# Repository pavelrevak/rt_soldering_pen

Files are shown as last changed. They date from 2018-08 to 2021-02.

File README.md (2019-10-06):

# RT soldering pen

oled4

[Manual]

This firmware is for my project [RT soldering pen](https://hackaday.io/project/18899-rt-soldering-pen)

You can buy HW at [Tindie](https://www.tindie.com/products/vlk/rt-soldering-pen/)

## Building and flashing

### Requirements

- [`arm-gcc`](https://developer.arm.com/open-source/gnu-toolchain/gnu-rm/downloads)
- [`cmake`](https://cmake.org/download/)
- `make` or [`ninja`](https://github.com/ninja-build/ninja)
- STM flashing SW and HW (ST-Link/V2 or any ST dev-kit, like Discovery or Nucleo board)

Building is possible on Linux, Mac and also on Windows

### Getting source

```sh
git clone --recursive https://github.com/pavelrevak/rt_soldering_pen.git
cd rt_soldering_pen
```

### Building

```sh
mkdir _build
cd _build
cmake -D CMAKE_TOOLCHAIN_FILE=../cmake/arm-none-eabi.cmake -D CMAKE_BUILD_TYPE=Release ..
make
```

### Flashing

Connect ST-Link or other SWD programmer:

#### HW v0.3

- G : GND
- C : SWCLK
- D : SWDIO

#### HW v1.0

- C : SWCLK
- G : GND
- D : SWDIO

If you have installed [pystlink](https://github.com/pavelrevak/pystlink) and is in search path just type:

```sh
make flash
```

If you have another flashing utility you can generate hex of binary file:

```sh
make srec
```

or building also support other targets `hex` and `bin`

Final files are saved in `_build` folder

[manual]: doc/MANUAL.md "Manual"
[oled4]: doc/oled4.png "Screenshot"

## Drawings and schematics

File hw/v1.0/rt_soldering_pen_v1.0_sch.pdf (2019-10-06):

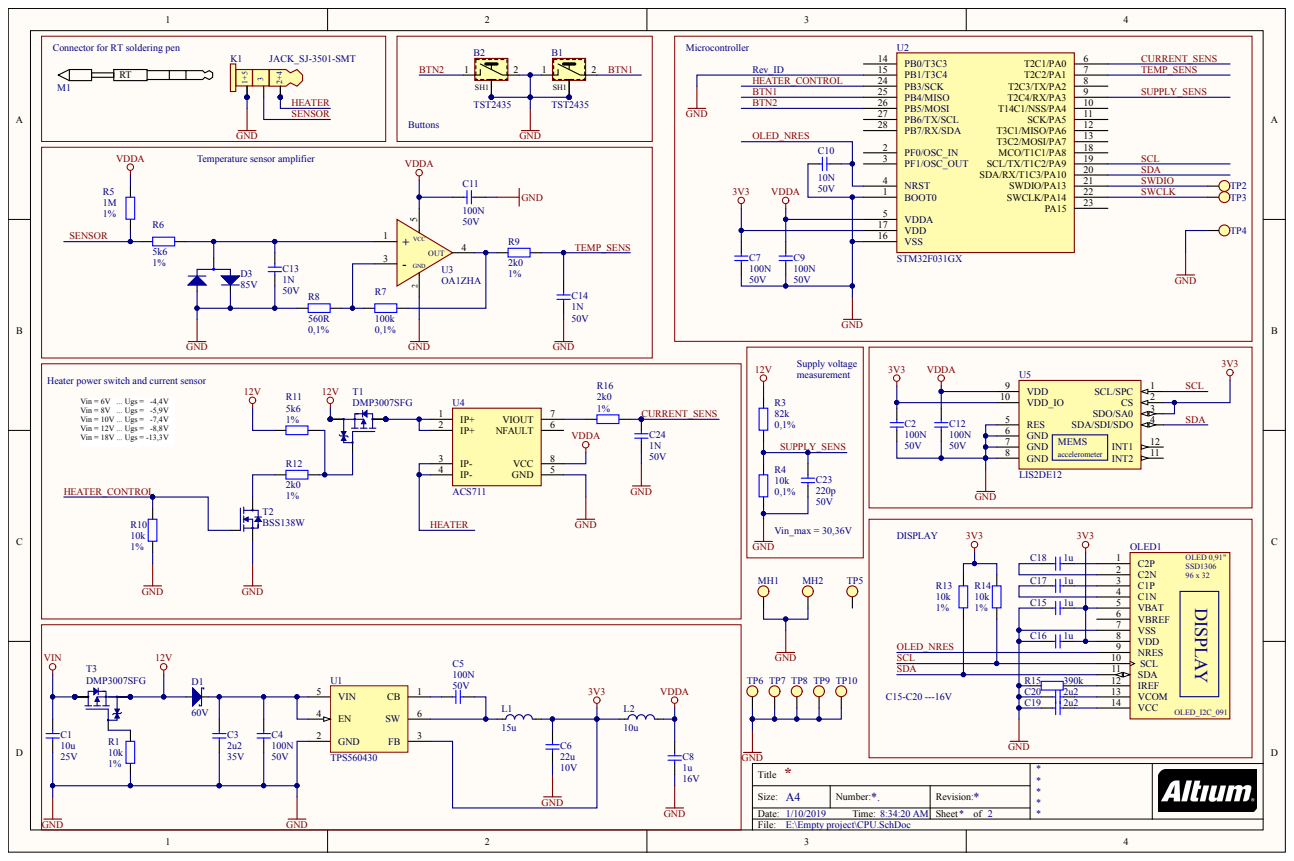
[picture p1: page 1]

Connector for RT soldering pen

Heater power switch and current sensor

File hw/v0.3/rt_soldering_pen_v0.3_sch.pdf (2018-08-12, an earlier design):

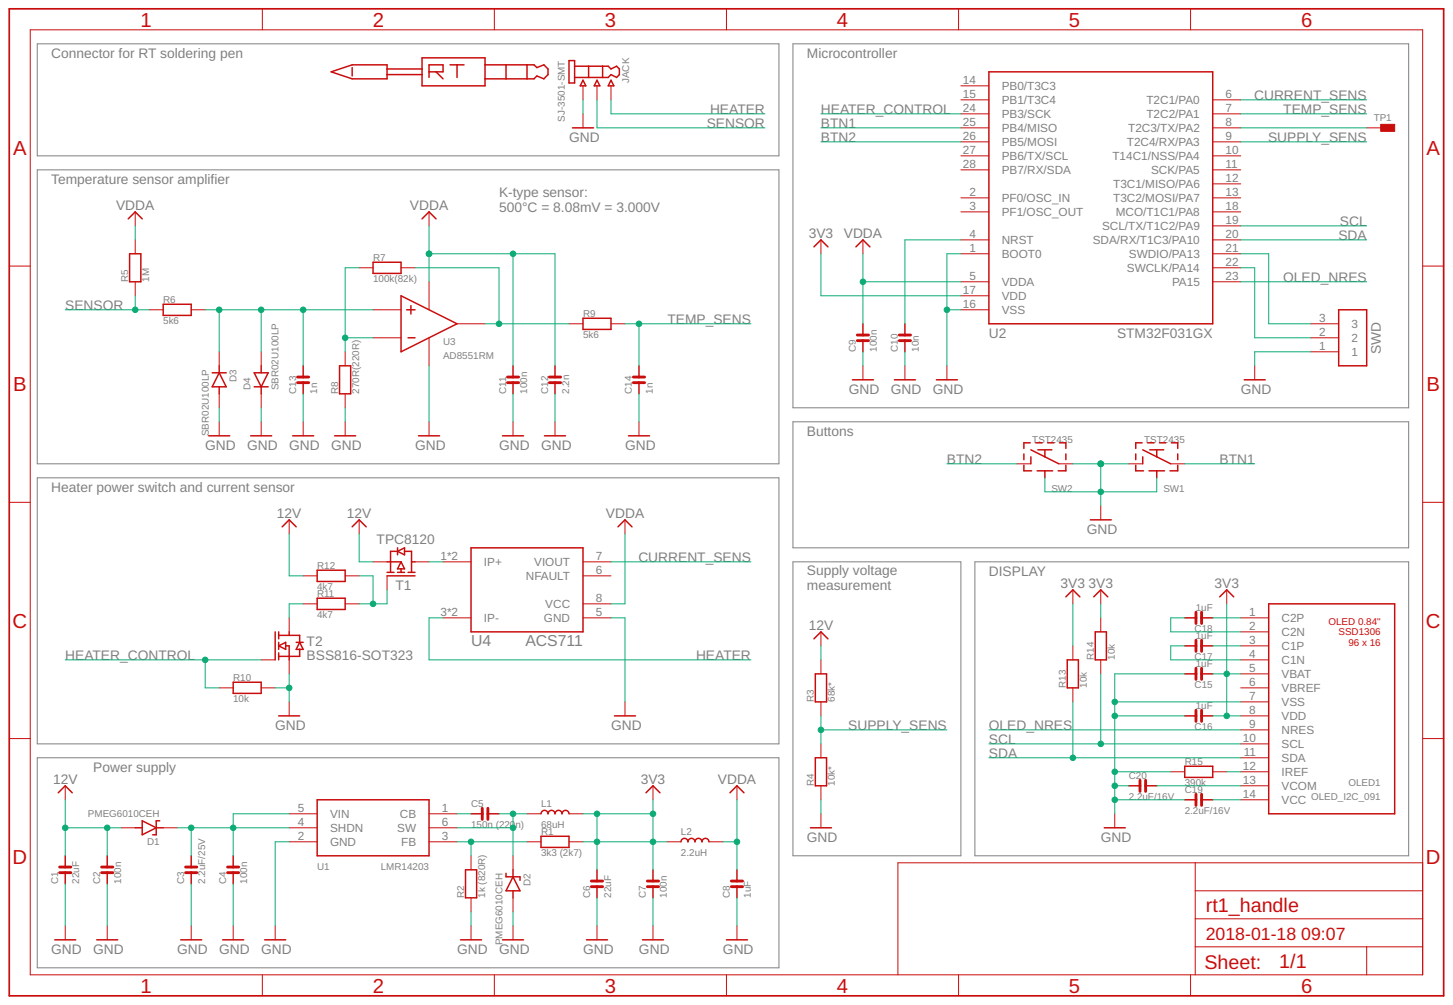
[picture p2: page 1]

17
16

Heater power switch and current sensor

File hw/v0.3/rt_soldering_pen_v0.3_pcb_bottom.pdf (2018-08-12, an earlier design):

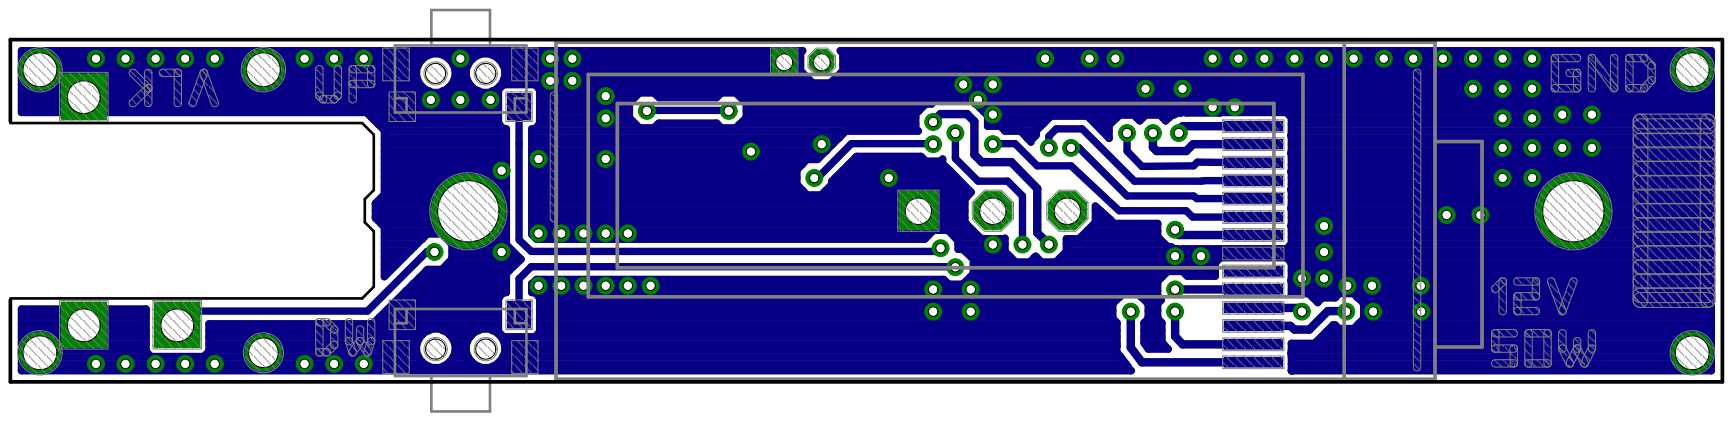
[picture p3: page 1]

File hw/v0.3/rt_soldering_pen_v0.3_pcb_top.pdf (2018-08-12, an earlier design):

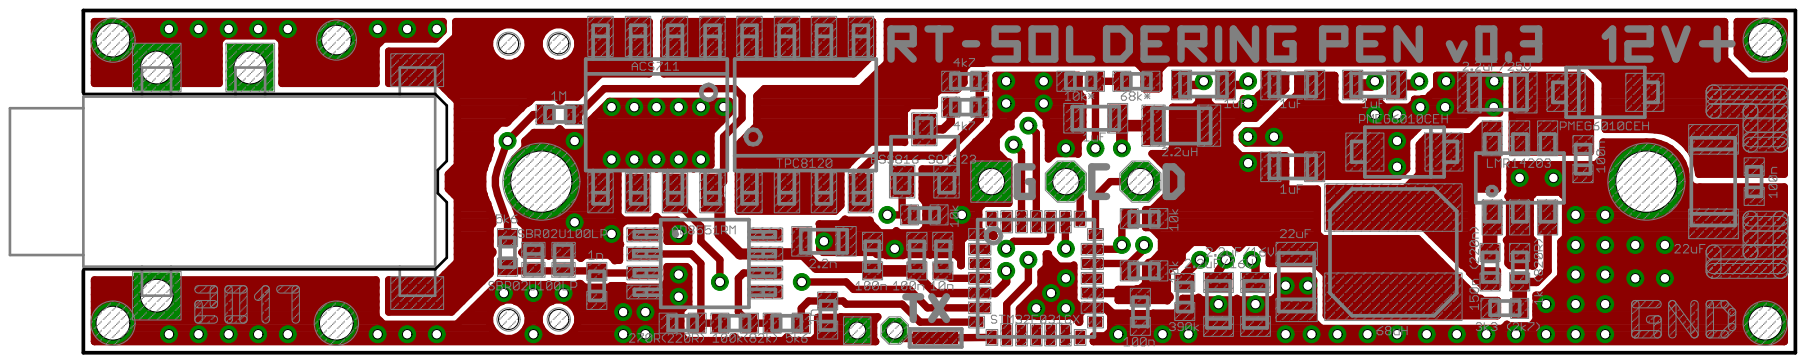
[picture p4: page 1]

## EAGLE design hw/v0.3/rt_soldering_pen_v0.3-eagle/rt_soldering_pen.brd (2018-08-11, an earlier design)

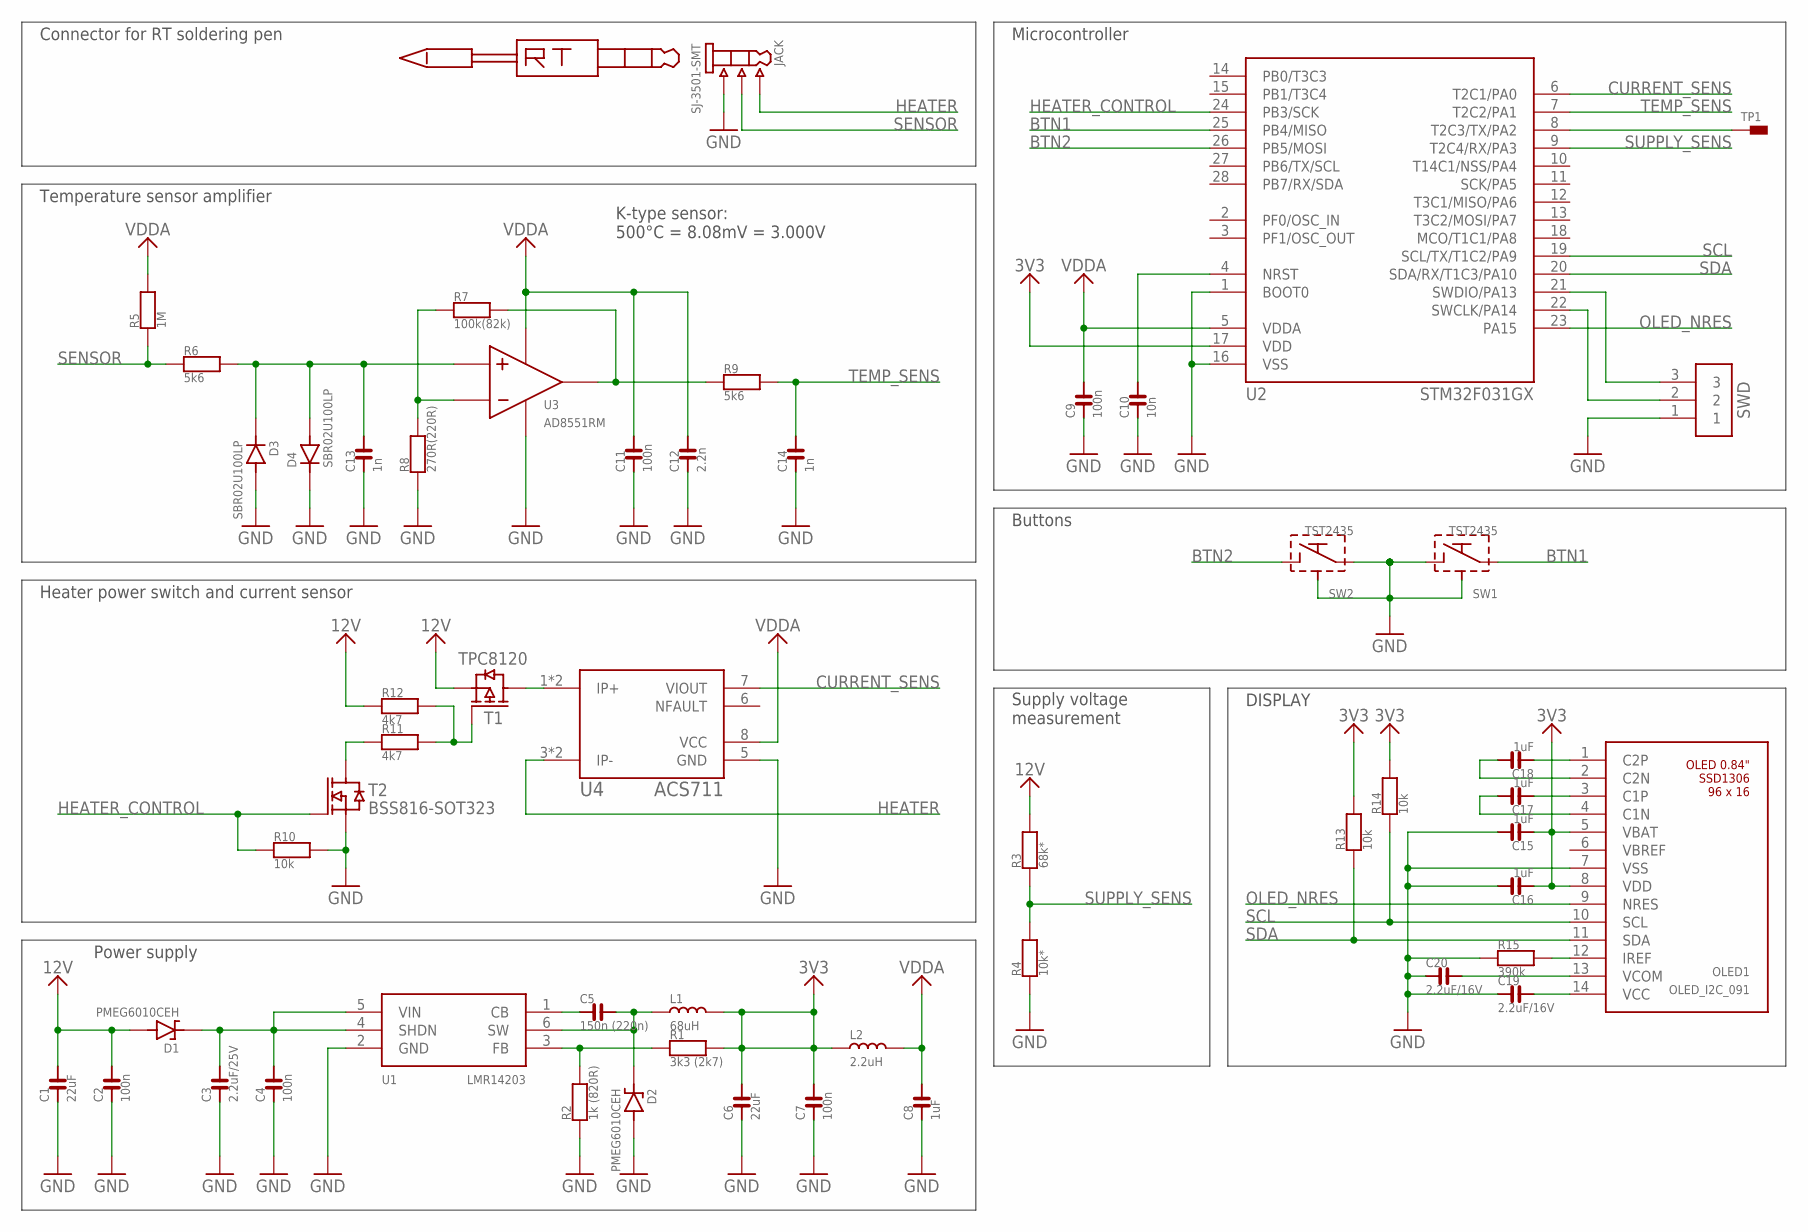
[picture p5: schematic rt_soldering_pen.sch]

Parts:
C1: 22uF; 1206
C2, C4, C7, C9, C11: 100n; 0402
C3: 2.2uF/25V; 0805
C5: 150n (220n); 0402
C6: 22uF; 0805
C8, C15, C16, C17, C18: 1uF; 0603
C10: 10n; 0402
C12: 2.2n; 0603
C13, C14: 1n; 0402
C19, C20: 2.2uF/16V; 0603
D1, D2: PMEG6010CEH; SOD123F
D3, D4: SBR02U100LP; DFN1006
JACK: SJ-3501-SMT
L1: 68uH; 1717
L2: 2.2uH; 0805
OLED1: OLED_I2C_091
R1: 3k3 (2k7); 0402
R2: 1k (820R); 0402
R3: 68k*; 0402
R4: 10k*; 0402
R5: 1M; 0402
R6, R9: 5k6; 0402
R7: 100k(82k); 0402
R8: 270R(220R); 0402
R10, R13, R14: 10k; 0402
R11, R12: 4k7; 0402
R15: 390k; 0402
RT: RT-1
SW1, SW2: TST2435
SWD: PINHEAD1X3X; PIN1X3
T1: TPC8120; SOIC8
T2: BSS816-SOT323; SOT23
TP1: TEST_PAD15X60; SMD_15_60
U1: LMR14203; SOT23-6
U2: STM32F031GX; UFQFPN28
U3: AD8551RM; MSOP8
U4: ACS711; SOIC8

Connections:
3V3: C6.2, C7.2, C15.1, C16.1, L1.2, L2.1, OLED1.5 (VBAT), OLED1.8 (VDD), R1.2, R13.2, R14.2, U2.17 (VDD)
12V: C1.2, C2.2, D1.A, R3.2, R12.1, T1.1 (S), T1.2 (S), T1.3 (S)
12V_DC: C3.2, C4.2, D1.C, U1.4 (SHDN), U1.5 (VIN)
BTN1: SW1.1, U2.25 (PB4/MISO)
BTN2: SW2.2, U2.26 (PB5/MOSI)
C1N: C17.2, OLED1.4 (C1N)
C1P: C17.1, OLED1.3 (C1P)
C2N: C18.2, OLED1.2 (C2N)
C2P: C18.1, OLED1.1 (C2P)
CURRENT_SENS: U2.6 (T2C1/PA0), U4.7 (VIOUT)
DEBUG_OUT: TP1.TP, U2.8 (T2C3/TX/PA2)
GND: C1.1, C2.1, C3.1, C4.1, C6.1, C7.1, C8.1, C9.1, C10.1, C11.1, C12.1, C13.1, C14.1, C15.2, C16.2, C19.1, C20.1, D2.A, D3.A, D4.C, JACK.1, JACK.5 (1), OLED1.7 (VSS), R2.1, R4.1, R8.1, R10.2, R15.1, SW1.2, SW1.EP1 (SHIELD), SW1.EP2 (SHIELD), SW2.1, SW2.EP1 (SHIELD), SW2.EP2 (SHIELD), SWD.1, T2.2 (S), U1.2 (GND), U2.1 (BOOT0), U2.16 (VSS), U3.4 (V-), U4.5 (GND)
HEATER: JACK.2, JACK.4 (2), U4.3 (IP-), U4.4 (IP-)
HEATER_CONTROL: R10.1, T2.1 (G), U2.24 (PB3/SCK)
HEATER_PWR: T1.5 (D), T1.6 (D), T1.7 (D), T1.8 (D), U4.1 (IP+), U4.2 (IP+)
IREF: OLED1.12 (IREF), R15.2
NRST: C10.2, U2.4 (NRST)
OLED_NRES: OLED1.9 (NRES), U2.23 (PA15)
POWER_SWITCH: R11.2, R12.2, T1.4 (G)
POWER_SWITCH_LOW: R11.1, T2.3 (D)
SCL: OLED1.10 (SCL), R14.1, U2.19 (SCL/TX/T1C2/PA9)
SDA: OLED1.11 (SDA), R13.1, U2.20 (SDA/RX/T1C3/PA10)
SENSOR: JACK.3, R5.1, R6.1
SENSOR_FEEDBACK: R7.1, R8.2, U3.2 (IN-)
SENSOR_IN: C13.2, D3.C, D4.A, R6.2, U3.3 (IN+)
SENSOR_OUT: R7.2, R9.1, U3.6 (OUT)
SUPPLY_CB: C5.1, U1.1 (CB)
SUPPLY_FB: R1.1, R2.2, U1.3 (FB)
SUPPLY_SENS: R3.1, R4.2, U2.9 (T2C4/RX/PA3)
SWDCLK: SWD.2, U2.22 (SWCLK/PA14)
SWDIO: SWD.3, U2.21 (SWDIO/PA13)
SWOUT: C5.2, D2.C, L1.1, U1.6 (SW)
TEMP_SENS: C14.2, R9.2, U2.7 (T2C2/PA1)
VCC: C19.2, OLED1.14 (VCC)
VCOM: C20.2, OLED1.13 (VCOM)
VDDA: C8.2, C9.2, C11.2, C12.2, L2.2, R5.2, U2.5 (VDDA), U3.7 (V+), U4.8 (VCC)

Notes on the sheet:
K-type sensor: 500°C = 8.08mV = 3.000V
SWD
Power supply
Heater power switch and current sensor
Temperature sensor amplifier
Connector for RT soldering pen
Microcontroller
DISPLAY
Supply voltage measurement
Buttons

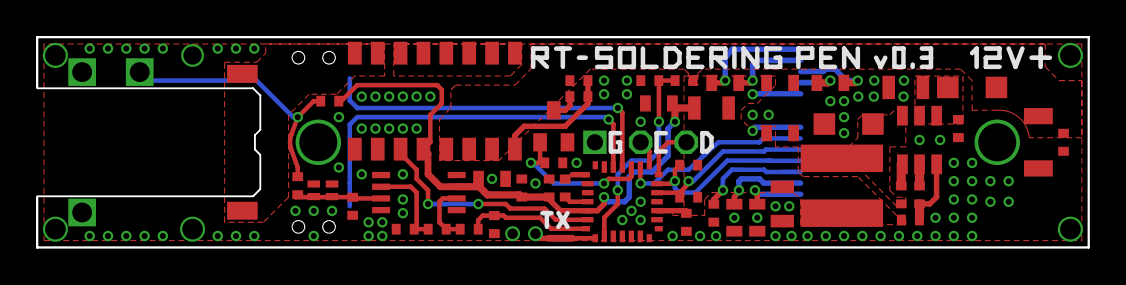
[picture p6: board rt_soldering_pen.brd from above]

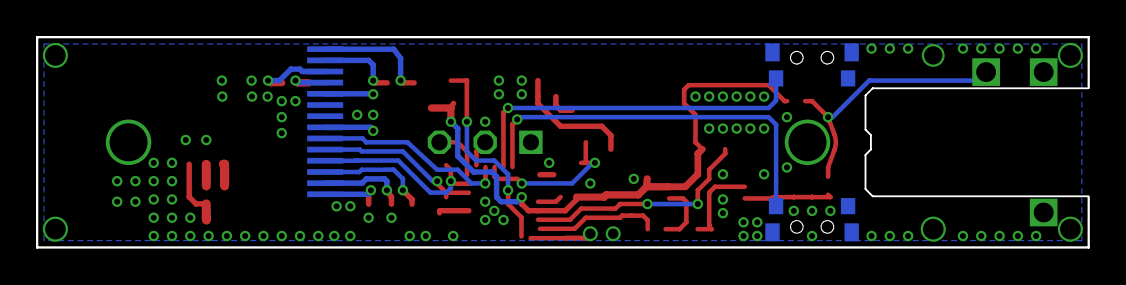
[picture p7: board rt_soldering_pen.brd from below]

Board: 2 copper layers, 58.4 x 11.7 mm, 54 parts (3 on the bottom side), 36 nets.

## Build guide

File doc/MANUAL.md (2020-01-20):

# RT soldering pen MANUAL

## Specs

- Supported pens: all Weller RT (RT, RTM, RTP and RTU) tips with 3.5mm JACK
- Operating voltage: 5 - 24V, recommended maximum:
  - 13V for RT, RTM and RTP tips
  - 24V for RTU tips
- absolute maximum voltage: 25V
- Supply current: pulse peaks to 6A @12V (average resistance of RT heating elements is 2 Ohm, so current depends on supply voltage)
- Supply current in idle: max 15mA
- Regulation: PSD (PID) regulator with PWM power transfer (125ms period)
- Set-point temperature: 50°C - 500°C (400°C with old HW v0.3)
- Maximum measurable tip temperature: 999°C (530°C + ambient temperature with old HW v0.3)
- Maximum heating power: is limited by SW to 40W or by supply voltage:
  - 20W @7V, 40W @10V (with RT, RTM and RTP tips)
  - 12W @7V, 40W @13V (with RTU tips)
- Heating speed: 30°C -> 300°C: about 4s with RT-2 pen and 40W limit
- Temperature accuracy: about +/-5°C
- Other features:
  - Celsius / Fahrenheit
  - right / left handed mode
  - normal / advanced mode display
  - High brightness mode
  - Auto turn off display to prevent OLED burning
- FW updating: by any SWD programmer (ST-Link) [actual firmware](https://github.com/pavelrevak/rt_soldering_pen/releases), firmware is still under active development.

## Powering

- supply pins are marked with GND, - or BLACK wire as negative pole and +12V, + or RED wire as positive pole.

### WARNING

- **Always check if RT tip is fully inserted before turning ON heating.** If is not fully inserted, then temperature measuring is not working and tip can be overheated. Protection for this will be created in future SW releases.

- on old HW v0.3 **be careful with connecting supply and always check polarity before turning ON!**
  - Although MCU is protected for reverse voltage by diode, power part is not protected. **If is connected RT tip, with reversed voltage then will heat on maximum power and also MOSFET transistor will overheat.** (this is for HW v0.3)
  - HW v1.0 has full reverse voltage protection with FET diode

- **Do not solder something under voltage if is powered from same supply, because RT tip is connected with GND. (for example inside car when pen is powered from lighter connector, or some AC power supplies where is negative pole connected to ground conductor).**
  - **MS** (Military Specs) tips have isolated tip from ground.

### Supply from AC power supply

Switching power supplies must be able to withstand high current pulses (12V/6A). These supplies has almost always connected negative pole with protective conductor.

Or you can use Transformer with good capacity and these supplies don't have connected minus pole to ground conductor.

### USB-C USB-PD

For that exists ZYPDS and similar modules - it is a converter from USB-PD to selected output voltage and current. But this is not tested and it should have some problems, because all the supply voltage is switched with PWM to 2 ohm load (inside RT tip) so: for 12V it is almost 6 Amps and in normal USB-PD is maximum rating 5A but only at 20V.

### Supply from battery

Best batteries for supply RT soldering pen are hobbyist LIPO 3S or 2S (but not full output power) with capacity at least 1Ah (with continuous discharge current at least 5A).

From my practice 2.2Ah 3S LIPO battery can last for about 5 to 10 hours of soldering.

### Hybrid power supply battery/USB(AC)

Also is possible to use small 3S LIPO battery about 0.5Ah / 20C and this battery will be continuously charged with small charger - steup-up from USB 5V (about 0.5A charging current) - this battery will work as capacitor with very high capacity. For that is enough also standard and cheap USB. and also is possible to work for some time without USB supply.

## Buttons

RT soldering pen has only two buttons: **UP** and **DOWN**. Firmware recognize different pressing states and combinations.

### Pressing states

- **PRESS** press button shortly (shorter than 1 sec) after release will be generated action
- **LONG** hold button longer than 1 sec, after 1 sec will be generated action "long"
- **HOLD** hold button and after 1 sec will be generated repeat actions

### General operating principles:

| | **UP** | **DOWN** | **BOTH** |
|---|---|---|---|
| **PRESS** | select, increase, scroll | select, decrease, scroll | heating off, exit menu  |
| **HOLD**  | edit | edit | enter menu, change item |
| **LONG**  | scroll, increase | scroll, decrease | - |

## Screens

Actually there are two screens.

### Main screen

#### Normal mode

oled6

Show very basic information

- preset temperatures and selected preset (with arrow)
- actual TIP temperature (if no TIP is attached, `--` is shown, if is detected error on pen, `Err` is shown)
- bar-graph - actual heating power.

#### Advanced mode

oled3

Show some verbose information:

- preset temperatures and selected preset (with arrow)
- actual TIP temperature (if no TIP is attached, CPU temperature is shown)
- consumed energy (this is restarted with power cycle)
- status
  - `NO RT TIP` - RT TIP is not attached (or TIP has broken temperature sensor)
  - `STANDBY` - standby mode (no heating), if blink: temperature is over 50°C
  - `IDLE` -  if during heating is not detected any work, after 5 sec is shown this message and after 30 sec is set standby mode
  - `OVERHEAT` - temperature of the TIP is higher than 500°C. (this can hapened due an error) if high temperature is detected, immediatelly is put into standby.
  - `BROKEN RT TIP!` - TIP has broken heating element (heating element resistance is more than 100 Ohm)
  - `SHORTED RT TIP!` - TIP has shorted heating element (heating element resistance is lower than 0.5 Ohm)
- actual heating power
- supply voltage
- supply voltage drop - show dropped voltage of power supply during heating, generally it depend on power supply resistance and resistance of wires

oled1
oled2
oled4

#### Left handed mode

Display is upside down, also with some rearrangements.

oled7
oled8

#### Editing preset temperatures

On **Main screen** are two (up and down) preset values, which you can easily change.
Editing is visible by blinking appropriate preset value.

**Entering edit mode:**

- **LONG** press **UP** or **DOWN** button of the appropriate preset temperature.

**Changing the edited preset temperature:**

- **UP** or **DOWN** button.

**Exiting edit preset value:**

- **PRESS** **BOTH** buttons.

### Menu screen

oled5
oled9

This screen show simple menu with:

- version information
- basic settings:
  - High Brightness
  - Advanced mode
  - Fahrenheit
  - Left handed
- some verbose information:
  - Total power
  - Heater power
  - Heater current
  - Heater resistance
  - CPU temperature
  - CPU supply
  - Current sensor error

**Entering menu screen:**

- in main screen **LONG** press of **BOTH** buttons

**Scrolling main screen**

-  **UP** or **DOWN** button

**Changing ON/OFF values:**

-  **LONG** press of **BOTH** buttons

**Exiting menu screen:**

-  **PRESS** **BOTH** buttons

*Exiting menu screen also store settings*

[oled1]: oled1.png "Screenshot"
[oled2]: oled2.png "Screenshot"
[oled3]: oled3.png "Screenshot"
[oled4]: oled4.png "Screenshot"
[oled5]: oled5.png "Screenshot"
[oled6]: oled6.png "Screenshot"
[oled7]: oled7.png "Screenshot"
[oled8]: oled8.png "Screenshot"
[oled9]: oled9.png "Screenshot"

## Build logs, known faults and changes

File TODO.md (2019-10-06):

### SW:
- ~~control display brightness~~
- ~~turn off display after long inactivity~~
- detect broken current sensor
- not fully inserted tip protection
- use current sensor magnetometer to enter sleep mode (magnet near the current sensor will enlarge offset error)
- use thermocouple type D curve to calculate tip temperature (it increases temperature measuring accuracy)
- standby should not blink if raw tip temperature is less than 10°C although tip temperature is higher than WARN_HOT_TIP_TEMP (50°C)
- overheating detection by temperature sensor
- in Fahrenheits mode increment by 5°F and round current temperature to 5°F
- I2C Read support
  - use temperature sensor in accelerometer instead sensor in CPU (HW v1.0)
  - use accelerometer to WAKE-UP (HW v1.0)
  - use accelerometer to detect free fall to turn OFF (HW v1.0)
- menu settings allow edit values
  - move PID and other constants to settings menu
  - configure maximum power output
- create screen "INFO" and move all information values there
- tool to tune PID regulation
- improve IDLE detection
- room to improve PID
- under voltage for LiPO protection
- screen saver ?

### HW:
- fix wrong connection to current sensor

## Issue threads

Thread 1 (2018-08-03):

Not issues but wishes

Kabron287, 2018-08-03:
Nice product
1. Accelerometer is higly desirable like in TS100
2. Go to Stanby Time adjustable from settings.

pavelrevak, 2018-08-08:
Adjustable standby timeout is planed feature
Accelerometer , there is no space on PCB, this need redesign.

Kabron287, 2018-08-08:
No need to redesign. Due to low pin-count it can easy placed on free PCB space and hand-wired.
You need Just to add the code.

pavelrevak, 2018-08-08:
yes, it is possible, but not for all devices ,-)

Kabron287, 2018-08-08:
What all devices?
On start SW search I2C if found MMA8652FC it use it, else not.

pavelrevak, 2018-08-09:
Ok, Now I understand what you want.
Yes, this is good idea and personally I also thought about it in the past, but at this moment there is still lot of work with the software. so, I need to postponed the idea for later.

pavelrevak, 2018-08-09:
But if you need something like "auto-standby" mode, there is still one possibility and without HW change. the current sensor also react on surrounding magnetic field (this magnetic field is compensated and subtracted from final measured current, but this "error" is possible to use for detect near magnetic field, so my idea is to put into stand small magnet which will be placed nearly to the current sensor location and if I detect higher magnetic field I put the iron into standby and if the field will lost I immediately wake up. this will be more easier.

Kabron287, 2018-08-09:
Good idea for a moment

pavelrevak, 2018-08-09:
You can see the magnetic field acting on the sensor in menu under: `Current sensor err:`

x893, 2018-08-11:
Hi,
possible change
1. ACS711ELCTR-12AB-T to ACS711KEXLT-15AB-T
2. LMR14203+1717+PMEG6010CEH to LMZM23600

pavelrevak, 2018-08-11:
Hi, thanks for suggestions.
Regarding ACS, I previously try to make design with this one, but with QFN it was much harder to layout it on two layer PCB, although it is smaller package, SO8 has so much space under package, so there was not a problem to wire other signals.
And LMZM23600 ... yes, I was looking on this one, but when I started the design it was problem to buy it, because it was very new and also has some special requirements from PCB.

Kabron287, 2018-08-16:
Made a simple case with the acrylic tube 16mm.
I had to make small recesses for the buttons.
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

elektrinis, 2018-09-01:
+1 for accelerometer. Bit frustrating to find it cold each time.

Also, is it possible to implement supply from USB C PD? There are several examples on github how to setup the USB for 12V 6A and it seems to be fairly simple. This would be extremely useful!

Kabron287, 2018-09-01:
**_There are several examples on github how to setup the USB for 12V 6A_**
Interesting, would you be kind to give some links?

elektrinis, 2018-09-01:
Arduino project: https://github.com/ReclaimerLabs/USB_PD
Other: https://github.com/ReclaimerLabs/USB-PD-Breakout
I also saw one for STM, can't find it quickly.

Kabron287, 2018-09-02:
Something have to be done with the current limitation alhoritm. Due to the very high starting current, most power supplies go into protection. There are not such behaviour in TS100 and TS80.
I guess soft start with variable PWM duty cicle required.

elektrinis, 2018-09-02:
I have also noticed that heater is being switched very slowly. You should PWM it at 16kHz, like most power electronics.

pavelrevak, 2018-09-04:
PWM period is 150ms, there are more reasons for that
1. low EMI
2. I can not measure temperature if power switch is ON, and after OFF I need wait at least 2ms (to stabilise temperature measure amplifier) and then measure for at least 8ms (there is more measurements for averaging) and to keep good duty cycle to maximise power if supply voltage is below 12V I need to make longer PWM.
3. also in every cycle I recalculate all measured values, calculate PID, redraw display with newly measured values, ..

Your power supply MUST withstand 2Ω load (e.g. 6A at 12V or 8A at 16V)
TS100/80 has higher heater resistance, so there is lower current.
I think TS100/80 has also low frequency PWM.

elektrinis, 2018-09-05:
Thank you for explaining. Not criticizing, just want to understand the issue better.
I have a fair amount of experience with BLDC/AC motor drives that usually run at 16kHz PWM and do much more measurements and calculations than in this case (read on FOC). The trick is to let PWM run on it's own dedicated timer-based peripheral, also use a peripheral to synchronize measurements at start of off state and then have your calculations running independently. Main objective is to free your CPU time by not micromanaging the PWM and only relatively infrequently updating cycle width. When you have high PWM frequency, you don't need to recalculate cycle-by-cycle.
Adding a small capacitor and, perhaps, inductor, will take care of EMI and will also allow to use lower power supply.

pavelrevak, 2018-09-05:
Yes, thats true, but there is still problem with thermocouple, which give only 8mV at 500°C this has common ground with heating element. and amplifier has some filters, so I need wait some time when it stabilise.
Another problem is that I used MOSFET with very low Rds-on but has one disadvantage that is slower and with higher frequencies will be not fully switched and then it will generate more heat. and this is another problem that I need to keep PCB cool as much as possible, because inside MCU is temperature sensor, which measure second end thermocouple (also reason why MCU is running on 8MHz and not at 48MHz).
I Have plan to try decrease period to about 50ms to have faster response of PID but I will do it later.

Regarding MCU there is also possibility to use STM32L031G6 which is pin compatible and has lower power consumption.

Or if you have some experience and time, you also can try to play with this, source is available.

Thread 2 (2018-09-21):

Eagle Mosfet lbr missing

Broatcast, 2018-09-21:
You missed to add your mosfet lbr to the repo. ;)

pavelrevak, 2018-10-23:
Done
51f855a429d37314537b0ec9da5aaea6c12ac7bc

Closed 2018-10-23.

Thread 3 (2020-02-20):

Hacking up a case - what screws?

qu1j0t3, 2020-02-20:
Hi,

I don't have the software to open your engineering drawings, so I was wondering if you can tell me if **M2** screws will definitely fit the two large pcb holes that seem to be about 2mm ø.

The clearance top and bottom looks to be less than 3mm so I am planning on using 3mm nylon spacers on both sides.

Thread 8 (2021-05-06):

Feature Request: Power-On-Demand Mode

wolfpackmars2, 2021-05-06:
POD mode.

An alternative mode where the iron is powered while pressing one of the buttons and shuts off when the button is released. The irons heat up quickly enough that this mode should be bearable for small soldering jobs. When pressed, the iron will wake and begin heating to it's set temp and then maintains that temp until the button is released, where the iron will power down.

In lieu of an audible alert when the set temp has been reached, flash "READY" in large print of the OLED.

To modify configuration while in this mode, press and hold both buttons for 3s, where the controller will wake and allow changing temperature/Mode/other parameters without heating the iron.

Can switch between Power-On-Demand/Standard modes in config.

Motivation: Increase efficiency when running iron from battery power.

I admit I have just received my first unit and haven't had much time with it, so I'm not familiar with the current features and operation. I DID want to document this thought while it was fresh in my mind.

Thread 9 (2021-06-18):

problem with RTM tip

messschuh, 2021-06-18:
i use the v.03 HW since round 3 years most time with RT8MS tip, now i got a new one, the RTM032S and they work a bit strange.
the temperature is not stable(+/- 10°) like the RT8MS (+/- 3°) and the powerregulation seems diffrent. at freeair the RT8MS power is nearly stable at round 3W, with the RTM032S  the power alternates from 0W to 6W to 0W @ round 3 seconds and with this tip the pen never detect an idle and because of this never goes to idle mode.
 the heat resitance shown at oled is for RTM032S 1.8Ohm and for RT8MS 2.1Ohm.  i testes SW v0.4.0 and v0.3.0 without diffrents.
only part of code i changed was the heating power, i reduced it to 35W because of 2 burned tips in the last 2 years.
i dont think this is normal, is this a known issue of this tip? can i try something?

swissfreek, 2021-06-18:
A friend of mine has also had three or four tips burn up over the past year. The issues I’ve identified with him is that he runs it at 400° Or more all the time to compensate for the (relatively) lower power compared to like an 80W soldering station. I never run mine higher than 400° and haven’t had a problem. I suspect these tips don’t like being run at high temp for long periods of time

pavelrevak, 2021-06-18:
RTM tips are very small, there is hard to tune PID regulation loop for all range of tips, for this tiny tip you can try to decrease amplification of all constants in PID (heating.hpp: PID_K_...)

messschuh, 2021-06-19:
thanks for fast reply.
most time i use mine at a range of 330°-360°C, for harder soldering jobs i use my 80W station. i´m not really sure constant high temperature  was problem of burning my tips, i will try it with the reduced Power (35W) and will see what happens.

what did u mean with "this tiny tip" ? the tips at all or especialy the RTM032S, because the RTM032S is a bit bigger than the RT8MS.
Ok, i tried some diffrent PID vlaues and now i have setting that works for me. I decresse P and I to 350, 300 and increase D to 75. now it needs a bit more time to get stable temperature but the settings works with my old and the new tip. maybe some finetuning is needed to get it works perfect, but for the moment it is ok.

pavelrevak, 2021-06-19:
Ah, I'm sorry, RTM032 is bigger, I was wrong with another RTP, which is smaller. but yes, it can help to tune the PID constants.

it will be good idea to make these constants editable from menu for fine-tune

messschuh, 2021-06-19:
yes  thats a good idea, maybe another good idea is to implement a PID autotune function. i know PID autotune from 3d-printers and that works well. but i dont know it  would pe possible to implement it.

messschuh, 2023-04-11:
short reply after nearly 2 years, no burned tips again and the "new" PID-settings works well. just at "higher" voltage ( 4s- range) the PID´s do not work perfect but acceptable good.

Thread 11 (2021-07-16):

WTF with stl???

Kabron287, 2021-07-16:
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
Maybe you had to warn about?

swissfreek, 2021-07-16:
The case was designed to be used with wires connected directly coming out the back of the PCB, to a battery connector (mine has about a meter of 22ga two-strand bonded silicone wire coming out the back with an XT60 at the end). For that, the ones I have printed come out fantastic. They have an absolutely perfect fit to the PCB. For your use, it would probably not be very hard to cut off the last five milimeters or so of the case and maybe carve the hole out a little bigger to fit your connector.

Kabron287, 2021-07-16:
Your stl files are for V1, mine is 0.3
They are not compatible!
That must be stated out!!!

swissfreek, 2021-07-16:
Sorry man, just trying to help. I'm not the one who created the project (that's Pawel Revak) and I'm not the one who designed the case (that's Otto Winter). However, the page does say that it's meant for HW v1.0:

https://hackaday.io/project/18899-rt-soldering-pen/log/171690-rt-pen-case

Kabron287, 2021-07-16:
Forget about. OLED is dead after trying to fit in this case

Kabron287, 2021-07-16:
What is OLED part number?

swissfreek, 2021-07-16:
Aw man, that sucks! I actually had the same thing happen to me as well. Even with HW 1.0, the cutout for the screen is off by a millimeter, maybe even less, and it will crack the edge of the screen if you force it. Pawel said Otto used a prototype version of the board, so it's a little off. On the plus side, it's fairly easy to replace the screen. I used this that I was able to get off Amazon overnight (I'm in the US).

https://www.amazon.com/Pieces-Display-Module-SSD1306-Screen/dp/B08TLXYKS6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

Downside is that I had to desolder it from the breakout board first, so it was extra work, but I didn't feel like waiting a month for a bare panel to ship to me from China. Once I replaced the screen, the trick is to put the screen in the case before you stick it down to the PCB with the double-sided tape. This way it will position itself properly and then you won't have a problem anymore.

swissfreek, 2021-07-16:
By the way, if you do buy the screen already attached to a breakout board like I did, a little heat will help release the double-sided tape without cracking the screen again. But be very careful with the heat, as it can affect the crystals in the screen. Just use a very tiny bit for a short time, that's all it takes.

Kabron287, 2021-07-16:
On the schematic it marked as 0.84" 96x16, but in you link it is 0.91"
Which is correct?

swissfreek, 2021-07-16:
I have HW v1.0, and I bought what I linked, and it fit perfectly, 1-for-1 replacement. If you have HW v0.3, it might use a smaller/lower res display, I'm not sure.

pavelrevak, 2021-07-16:
v0.3 also has 0.91, (it is mistake in schematic) for both is possible to put also 0.84 (16x96), but software is made for only 0.91 (32x128)

Kabron287, 2021-07-16:
I guess corrections will follow

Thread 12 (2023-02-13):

can you publish v1.1 HW info?

eliocor, 2023-02-13:
Since it is almost 2 years the Tindie shop does not offer anymore your soldering pen, will you be so kind to publish the v1.1 schematics and (if possible) the gerbers of the new PCB?

paciotti, 2023-02-22:
It will be really appreciated!

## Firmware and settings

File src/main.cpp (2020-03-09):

#include "io/reg/cortexm/nvic.hpp"
#include "drv/watchdog.hpp"
#include "board/clock.hpp"
#include "board/systick.hpp"
// #include "board/debug.hpp"
#include "board/hwid.hpp"
#include "board/adc.hpp"
#include "board/i2c.hpp"
#include "board/buttons.hpp"
#include "board/display.hpp"
#include "heating.hpp"
#include "display.hpp"
#include "settings.hpp"

class MainClass {
    unsigned last_ticks = 0;

    Settings _settings;
    Heating _heating;
    Display _display;

    void _process(unsigned delta_ticks) {
        _display.process(delta_ticks);
        if (_heating.process(delta_ticks) == Heating::State::STOP) {
            _display.draw();
            _heating.start();
            drv::Watchdog::refresh();
        }
    }

    void _init_hw() {
        board::Clock::get_instance().init_hw();
        board::Systick::get_instance().init_hw();
        // board::debug.init_hw();
        board::HwId::get_instance().init_hw();
        board::Heater::get_instance().init_hw();
        board::Buttons::get_instance().init_hw();
        board::Adc::get_instance().init_hw();
        board::I2c::get_instance().init_hw();
        board::display.init_hw();
        drv::Watchdog::enable(200, 100);  // time and window in ms
    }

public:
    MainClass() :
    _heating(_settings),
    _display(_heating, _settings) {}

    void run() {
        _init_hw();
        io::Nvic::isr_enable();

        board::display.init();
        _heating.init();
        _heating.start();

        // board::debug.dbg << lib::IOStream::endl << "started.." << lib::IOStream::endl;
        last_ticks = board::Systick::get_instance().get_counter();

        while (true) {
            unsigned delta_ticks = last_ticks;
            last_ticks = board::Systick::get_instance().get_counter();
            delta_ticks = ((1 << board::Systick::DIV_BITS) - 1) & (delta_ticks - last_ticks);
            _process(delta_ticks);
        }
    }
};

void main_app() {
    MainClass main_class;
    // start application
    main_class.run();
}

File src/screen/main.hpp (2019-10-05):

#pragma once

#include "screen/screen.hpp"
#include "lib/font.hpp"
#include "lib/stringstream.hpp"
#include "preset.hpp"
#include "heating.hpp"
#include "settings.hpp"

namespace screen {

class Main : public Screen {

    static const int PRESET_TEMPERATURE_STEP = 5 * 1000;  //  10 degree C
    static const int ROUNDING_TEMPERATURE = 500;
    static const int IDLE_MESSAGE_MS = 5000;
    static const int WARN_HOT_TIP_TEMP = 50 * 1000;

    board::Display::Fb &_fb = board::display.get_fb();
    Heating &_heating;
    Preset &_preset;
    Settings &_settings;

    void _preset_selected(int x, int y, bool is_on) {
        x = _fb.draw_char(x, y, is_on ? '\275' : '\274' , lib::Font::num13);
    }

    /** display temperature in 1/1000 degree Celsius */
    template<class Tfl, class Tfs>
    void _temperature(int x, int y, int temperature, const Tfl font_large, const Tfs font_small) {
        lib::StringStream<4> ss;
        if (_settings.get_fahrenheit()) {
            // Fahrenheit
            ss.i(temperature * 9 / 5000 + 32, 3, ' ');
        } else {
            // Celsius
            ss.i(temperature / 1000, 3, ' ');
        }
        x = _fb.draw_text(x, y, ss.get_str(), font_large);
        if (_settings.get_fahrenheit()) {
            // Fahrenheit
            _fb.draw_text(x, y, "\260F", font_small);
        } else {
            // Celsius
            _fb.draw_text(x, y, "\260C", font_small);
        }
    }

    /** display voltage in millivolts */
    void _voltage_mv(int x, int y, int voltage_mv) {
        lib::StringStream<5> ss;
        if (voltage_mv < 10 * 1000) {
            ss.dec(voltage_mv / 10, 1, 2, '\240');
        } else {
            ss.dec(voltage_mv / 100, 2, 1, '\240');
        }
        x = _fb.draw_text(x, y, ss.get_str(), lib::Font::num7);
        _fb.draw_char(x, y, 'V', lib::Font::sans8);
    }

    /** display drop voltage in millivolts */
    void _drop_voltage_mv(int x, int y, int voltage_mv) {
        lib::StringStream<6> ss;
        ss.dec(voltage_mv / 10, 2, 2, '\240');
        x = _fb.draw_text(x, y, ss.get_str(), lib::Font::num7);
        _fb.draw_char(x, y, 'V', lib::Font::sans8);
    }

    /** display current in mA */
    void _current_ma(int x, int y, int current_ma) {
        lib::StringStream<7> ss;
        ss.dec(current_ma, 2, 3, '\240');
        x = _fb.draw_text(x, y, ss.get_str(), lib::Font::num7);
        _fb.draw_char(x, y, 'A', lib::Font::sans8);
    }

    /** display power in milliwatts */
    void _watts_mw(int x, int y, int watts_mw) {
        lib::StringStream<5> ss;
        ss.dec(watts_mw / 100, 2, 1, '\240');
        x = _fb.draw_text(x, y, ss.get_str(), lib::Font::num7);
        _fb.draw_char(x, y, 'W', lib::Font::sans8);
    }

    /** display power in milliwatts */
    void _energy(int x, int y, int energy_mwh) {
        lib::StringStream<5> ss;
        if (energy_mwh < 10000) {
            ss.dec(energy_mwh / 10, 1, 2, '\240');
        } else {
            ss.dec(energy_mwh / 100, 2, 1, '\240');
        }
        x = _fb.draw_text(x, y, ss.get_str(), lib::Font::num7);
        _fb.draw_text(x, y, "Wh", lib::Font::sans8);
    }

    int _edit_blink = 0;

    void _draw_tip_temperature(int offset) {
        _temperature(offset, 10, _heating.get_real_tip_temperature_mc() + 500, lib::Font::num22, lib::Font::num7);
    }

    int status_blink = 0;

    void _draw_tip_temperature_large(int offset) {
        if (status_blink++ >= 3) status_blink = 0;
        if (_preset.is_standby()) {
            if (_heating.getTipSensorStatus() == Heating::TipSensorStatus::OK) {
                if (
                    (_heating.getHeatingElementStatus() == Heating::HeatingElementStatus::BROKEN) ||
                    (_heating.getHeatingElementStatus() == Heating::HeatingElementStatus::SHORTED)
                ) {
                    _fb.draw_text(offset, 0, "Err", lib::Font::num32);
                    return;  // do not show energy
                }
            } else if (_heating.getTipSensorStatus() == Heating::TipSensorStatus::BROKEN) {
                _fb.draw_text(offset, 0, " --", lib::Font::num32);
                return;
            } else if (_heating.getTipSensorStatus() == Heating::TipSensorStatus::OVERHEAT) {
                _fb.draw_text(offset, 0, " 0H", lib::Font::num32);
                return;
            }
            // during standby and temperature is higher than 50 degree Celsius, temperature will blink
            if (_heating.get_real_tip_temperature_mc() >= WARN_HOT_TIP_TEMP && status_blink > 2) return;
        }
        _temperature(offset, 0, _heating.get_real_tip_temperature_mc() + 500, lib::Font::num32, lib::Font::num13);
    }
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

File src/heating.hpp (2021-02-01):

#pragma once

#include "board/clock.hpp"
#include "board/heater.hpp"
#include "board/hwid.hpp"
#include "board/adc.hpp"
#include "lib/pid.hpp"
#include "preset.hpp"

/** Class for controlling heating and measuring cycle
*/
class Heating {
 public:
    static const int PERIOD_TIME_MS = 125;  // ms
    static const int STANDBY_TIME_MS = 30000;  // ms
    static const int PID_K_PROPORTIONAL = 450;
    static const int PID_K_INTEGRAL = 1000;
    static const int PID_K_DERIVATE = 50;
    static const int HEATING_POWER_MAX_MW = 40 * 1000;  // mW
    static const int IDLE_MIN_TIME_MS = 3;  // ms
    static const int STABILIZE_TIME_MS = 2;  // ms
    static const int HEATING_MIN_POWER_MW = 100;  // mW
    static const int TIP_MAX_CURRENT_MA = 9000;  // mA
    static const int SUPPLY_VOLTAGE_HEATING_MIN_MV = 4300;  // mV
    static const int RTM_SUPPLY_VOLTAGE_MAX_MV = 14000;  // mV
    static const int RTU_SUPPLY_VOTLAGE_MAX_MV = 25000;  // mV
    static const int TIP_RESISTANCE_SHORTED_MO = 500;  // mOhm
    static const int TIP_RESISTANCE_MIN_MO = 1500;  // mOhm
    static const int TIP_RESISTANCE_MAX_MO = 2500;  // mOhm
    static const int TIP_RESISTANCE_BROKEN_MO = 100000;  // mOhm
    static const int OVERHEAT_TEMPERATURE_MC_HW0X = 500 * 1000;  // 1/1000 degree Celsius
    static const int OVERHEAT_TEMPERATURE_MC = 600 * 1000;  // 1/1000 degree Celsius

    enum class State {
        STOP,
        START,
        HEATING,
        STABILIZE,
        IDLE,
    } _state = State::STOP;

    enum class HeatingElementStatus {
        UNKNOWN,
        OK,
        SHORTED,
        LOW_RESISTANCE,
        HIGH_RESISTANCE,
        BROKEN,
    } _heating_element_status = HeatingElementStatus::UNKNOWN;

    enum class TipSensorStatus {
        UNKNOWN,
        OK,
        OVERHEAT,
        BROKEN,
        SHORTED,
    } _tip_sensor_status = TipSensorStatus::UNKNOWN;

 private:
    Settings &_settings;
    Preset _preset;
    lib::Pid _pid;

    uint64_t _uptime_ticks = 0;
    int64_t _requested_power_uw_period_ticks = 0;  // uW * _required_period_ticks
    int64_t _energy_uw_ticks = 0;  // uW * CORE_FREQ
    int64_t _steady_ticks = 0;  // ticks when power is steady
    unsigned _required_period_ticks = 0;
    unsigned _period_ticks = 0;

    unsigned _measure_ticks = 0;
    int _measurements_count = 0;

    int _requested_power_mw = 0;  // mW
    int _power_mw = 0;  // mW
    int _cpu_voltage_mv_heat = 0;  // mV
    int _cpu_voltage_mv_idle = 0;  // mV
    int _supply_voltage_mv_heat = 0;  // mV
    int _supply_voltage_mv_idle = 0;  // mV
    int _supply_voltage_mv_drop = 0;  // mV
    int _heater_current_ma = 0;  // mA
    int _heater_current_ma_error = 0;  // mA
    int _heater_resistance_mo = 0;  // mOhm
    int _tip_temperature_mc = 0;  // 1/1000 degree C
    int _cpu_temperature_mc = 0;  // 1/1000 degree C

    int _average_requested_power = 0;
    int _average_requested_power_short = 0;

    int64_t _ms2ticks(const int64_t time_ms) const {
        return time_ms * board::Clock::CORE_FREQ / 1000;
    }

    int _ticks2ms(const int64_t ticks) const {
        return static_cast<int>(ticks * 1000 / board::Clock::CORE_FREQ);
    }

    void _state_stop() {
        bool stop = getTipSensorStatus() != Heating::TipSensorStatus::OK;
        stop |= getHeatingElementStatus() == Heating::HeatingElementStatus::SHORTED;
        stop |= getHeatingElementStatus() == Heating::HeatingElementStatus::BROKEN;
        stop |= get_steady_ms() > STANDBY_TIME_MS;
        if (stop) {
            _preset.set_standby();
        }
    }

    void _state_start() {
        // reset meters
        _measure_ticks = 0;
        _measurements_count = 0;
        _cpu_voltage_mv_heat = 0;
        _supply_voltage_mv_heat = 0;
        _heater_current_ma = 0;
        _power_mw = 0;
        if (_requested_power_mw < HEATING_MIN_POWER_MW) {
            board::Adc::get_instance().measure_idle_start();
            _requested_power_mw = 0;
            _requested_power_uw_period_ticks = 0;
            _steady_ticks = 0;
            _state = State::IDLE;
            return;
        }
        // calculating derivation of requested power
        // (for auto standby)
        // TODO rework this code
        _average_requested_power_short *= 2;
        _average_requested_power_short += _requested_power_mw;
        _average_requested_power_short /= 3;
        _average_requested_power *= 9;
        _average_requested_power += _requested_power_mw;
        _average_requested_power /= 10;
        int derivate_requested_power = _average_requested_power_short - _average_requested_power;
        if ((derivate_requested_power > 150) || derivate_requested_power < -200) {
            _steady_ticks = 0;
        }
        // enable heater (PWM ON)
        board::Heater::get_instance().on();
        // measure start
        board::Adc::get_instance().measure_heat_start();
        _heating_element_status = HeatingElementStatus::UNKNOWN;
        _tip_sensor_status = TipSensorStatus::UNKNOWN;
        _state = State::HEATING;
    }

    int _get_compensated_heater_current() {
        int current = board::Adc::get_instance().get_heater_current_ma();
        current -= _heater_current_ma_error;
        return current;
    }

    void _cumulate_heating_measured_values() {
        _cpu_voltage_mv_heat += board::Adc::get_instance().get_cpu_voltage_mv();
        _supply_voltage_mv_heat += board::Adc::get_instance().get_supply_voltage_mv();
        _heater_current_ma += _get_compensated_heater_current();
        _measurements_count++;
    }

    int64_t _get_power_energy_uw_period_ticks() const {
        int64_t energy = _supply_voltage_mv_heat / _measurements_count;
        energy *= _heater_current_ma / _measurements_count;
        energy *= _measure_ticks;
        if (energy < 0) energy *= -1;
        return energy;
    }

    bool _check_heating_limits() const {
        // check over current
        if ((_heater_current_ma / _measurements_count) > TIP_MAX_CURRENT_MA) return true;
        // check reached power
        if (_get_power_energy_uw_period_ticks() > _requested_power_uw_period_ticks) return true;
        // check low voltage
        if (_supply_voltage_mv_heat / _measurements_count < SUPPLY_VOLTAGE_HEATING_MIN_MV) return true;
        // check reached time
        if (_period_ticks > (_required_period_ticks - _ms2ticks(STABILIZE_TIME_MS + IDLE_MIN_TIME_MS))) return true;
        // OK
        return false;
    }

    void _calculate_total_energy() {
        int64_t power_uw_period_ticks = _supply_voltage_mv_heat;
        power_uw_period_ticks *= _heater_current_ma;
        power_uw_period_ticks *= _measure_ticks;
        _power_mw = static_cast<int>(power_uw_period_ticks / _required_period_ticks / 1000);
        _energy_uw_ticks += power_uw_period_ticks;
        _measure_ticks = 0;
    }
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

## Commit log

2018-03-10 removed pure_virtual_stub, moved button class to lib, moved analog values calculation to board.adc
2018-03-10 removed interrupt for adc dma
2018-03-18 improved handling buttons
2018-06-16 heating state machine separated from main
2018-06-17 bugfixes - heating is now working
    [main.cpp]
2018-06-18 moved heating and preset to src folder
2018-06-20 rewrited stream and printing on display with stringstream
2018-06-20 compensated current sensor to increase accuracy
2018-06-22 moved heat processes from main.cpp into heating.hpp
2018-06-28 cleaned board/ADC module
2018-06-29 ADC: code cleaning
2018-06-29 ADC: small code refactoring
2018-06-29 heating: code refactoring and cleaning (no functionality changed)
2018-06-30 added undervoltage limit to limit heating power if batery has too low voltage (actually is set to 4.3V)
    [heating.hpp]
2018-07-01 add magic word before framebuffer to easy find framebuffer in memory and take screenshots
2018-07-02 fixed issue with current compensation
    [heating.hpp]
2018-07-06 corrected naming of variables with to
    [adc.hpp, heating.hpp, main.hpp]
2018-07-12 added script for testing buttons on HW without connected display
2018-07-13 fixed long buttons press
2018-07-23 added option for advanced screen, now is default screen simple (show only preset and measured temperature) and switching to advanced screen is by menu option
2018-07-29 detecting shortcut on RT TIP (this state is still not processed to protect RT tip)
    [adc.hpp, heating.hpp]
2018-08-07 increased current limit for heater from 6A to 9A, now it will work at 18V supply
2018-08-08 increased minimum set-point temperature to 50 degree C, use minmax lib, added const to methods and code cleaning
2018-08-08 added overheat limit (to 500 degree Celsius), in case of overheat will be immediatelly switched into standby + dissable heating if is standby mode
    [heating.hpp]
2018-08-08 heating: added const, removed unused constant
2018-08-08 show overheat info on display (in simple mode show OH)
    [main.hpp]
2018-08-08 rewrited PID, changed some modifications of PID and changed constants, now is faster heating, smaller overshot, faster reaction during soldering, .. but there is still room for improvements
2018-08-08 simple mode: in standby if temperature is more than 50 degree Celsius will temperature blink
2018-08-09 saving preset temperatures
2018-08-12 added schematic pdf + renamed folder
    [rt1_handle.brd, rt1_handle.sch]
2018-08-12 pdf: schematic + pcb
2018-09-03 fixed warnings Wconversion, Wold-style-cast and Wcast-align
    [heating.hpp, i2c.hpp]
2018-09-08 better power bargraph in simple main screen
2018-10-19 added missing mosfet library
2019-10-05 updated buttons testing script to exit when both buttons are pressed longer than 1s
2019-10-06 increased temperature range for HW v1.0
2019-10-06 added schematic for hw v1.0
    [rt_soldering_pen.brd, rt_soldering_pen.sch]
2020-03-09 moved eagle folder
    [rt_soldering_pen.brd, rt_soldering_pen.sch]
2021-01-28 Add new maximum voltage
    New maximum voltage constant added. Now there are two, one for RTM tips (14V) and one for RTU tips (25V).
